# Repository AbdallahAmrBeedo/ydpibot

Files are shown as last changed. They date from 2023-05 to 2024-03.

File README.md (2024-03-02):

# **YDPIbot**

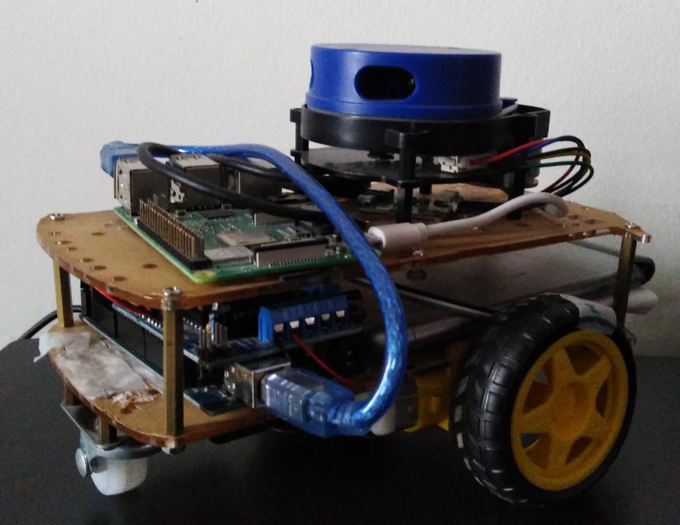
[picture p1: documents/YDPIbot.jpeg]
ydlidar X4


YDPIbot is an open platform differential drive mobile robot that uses a Raspberry Pi, an Arduino Mega, a YDLidar, a motor shield, an IMU, and encoders to perform autonomous navigation and mapping tasks. YDPIbot is an affordable and easy-to-assemble robot that is designed to be an educational tool for students and hobbyists who are interested in learning about robotics and autonomous systems.

---------------------------
# Assembly

To assemble YDPIbot, you will need the following components:

- Raspberry Pi 3 model B+
- YDLidar x4
- Arduino Mega
- Motor driver shield
- IMU (MPU6050)
- Optical encoders
- 2 DC motors
- 2 Wheels
- 1 Caster wheel
- Batteries with holder
- Power bank

Follow these steps to assemble YDPIbot:

1. Connect the Arduino Mega to the motor driver shield and the optical encoders and MPU6050 according to the pinout diagram provided in the documentation.
2. Connect the IMU to Raspberry Pi using the I2C interface and follow the instructions in the [mpu6050 pkg](https://github.com/PigeonSensei/pigeon_imu_driver/tree/master/mpu6050).
3. Mount the YDLidar on top of the robot using screws.
4. Mount the Raspberry Pi and the motor driver shield on the chassis of the robot using screws and standoffs.
5. Connect the DC motors to the motor driver shield and attach the wheels to the motor shafts.
6. Attach the optical encoders to the motors using the mountingbrackets provided in the kit.
7. Attach the caster wheel to the bottom of the robot chassis.
8. Install the batteries or power banks on the robot and connect them to the Arduino Mega and the motor driver shield.

---------------------------
# Installation

To use YDPIbot, you will need to install the following dependencies:

- [Python 3](https://www.python.org/downloads/)
- [Ubiquity Robotics image - Ubuntu 20.04](https://learn.ubiquityrobotics.com/noetic_pi_image_downloads) for rasberry pi
- [ROS Noetic](http://wiki.ros.org/noetic/Installation) - the ubiquity robotics image have ROS noetic already-
- [YDLidar pkg](https://github.com/PinkWink/ydlidar)
- [MPU6050](https://github.com/PigeonSensei/pigeon_imu_driver/tree/master/mpu6050)
- Robot Pose EKF
- Hector Mapping
- Rosserial
---------------------------
### Installing Ubuntu20.04 on Raspberry PI

We recommend installing Ubuntu 20.04 and ROS noetic on the Raspberry Pi using the Ubiquity Robotics image. Follow these steps to install Ubuntu 20.04 using the Ubiquity Robotics image:

1. Download the Ubiquity Robotics image for Raspberry Pi from the [Ubiquity Robotics](https://learn.ubiquityrobotics.comnoetic_pi_image_downloads)

2. Flash the image to an SD card using a tool like Raspberry Pi Imager.

3. Insert the SD card into the Raspberry Pi and power it on.

4. Follow the on-screen instructions to complete the Ubuntu 20.04 installation process.

---------------------------
### Installing YDlidar pkg

To install the YDLidar pkg, follow these steps:

1. Open a terminal on your Raspberry Pi.

2. Clone the YDLidar repository using the following command:

    `git clone https://github.com/PinkWink/ydlidar.git`

3. Follow the instructions in the [README file](https://github.com/PinkWink/ydlidar) to build the YDLidar pkg.

4. Run some demo with the lidar to check if it's working.

---------------------------
### Installing MPU6050 pkg

To install the MPU6050 pkg, follow these steps:

1. Open a terminal on your Raspberry Pi.

2. Clone the MPU6050 repository using the following command:

    `https://github.com/PigeonSensei/pigeon_imu_driver/tree/master/mpu6050`

3. Install wiringPi library from [here](http://wiringpi.com/download-and-install/)

4. Run some demo with the IMU to check if it's working.

---------------------------
### Installing YDPIbot pkg

To install the YDPIbot package, follow these steps:

1. Open a terminal on your Raspberry Pi or PC.

2. Navigate to your `catkin_ws/src` directory

3. Clone the YDPIbot repository using the following command:

    `git clone https://github.com/AbdallahAmrBeedo/ydpibot.git`

4. Navigate back to the main catkin_ws to build the pkg using the command:

    `catkin_make`

---------------------------
### Uploading Arduino Code

1. Open Arduino IDE and connect the arduino to your PC

2. Choose from tools/boards Arduino Mega 2560 and choose the port (Usually **/dev/ttyACM0** if you are running from Ubuntu)

3. Open the code in `~/catkin_ws/src/ydpibot/ydpibot_bringup/YDPIbot/YDPIbot.ino`

4. Upload the code and connect the Arduino to the raspberry pi.

---------------------------
## Usage
For using the robot hardware, just open a terminal on the Raspberry pi and run the following command:

`roslaunch ydpibot_bringup robot.launch`

and wait until you see the massage `Sensors calibrated, Start!`

Now, you can run any other pkg to do anything!

---------------------------

For using the robot simulation, just open a terminal on the PC and run the following command:

`roslaunch ydpibot_description robot.launch`

Now, you can run any other pkg to do anything!

---------------------------
## Contributing

We welcome contributions from other developers! If you would like to contribute to YDPIbot, please follow these guidelines:

1. Fork the YDPIbot repository to your own GitHub account.
2. Create a new branch for your feature or bug fix.
3. Make your changes and test them thoroughly.
4. Submit a pull request to the main YDPIbot repository with a clear description of your changes.

---------------------------
## Credits

YDPIbot was created by Abdallah Amr, Mostafa Osama, Tarek Shohdy, and Yomna Omar from Egypt-Japan University of Science and Technology. We would like to acknowledge the following libraries and tools that were used in the development of this project:

- [YDLidar SDK](https://www.ydlidar.com/products/view/5.html)
- [Adafruit Motor Shield library](https://learn.adafruit.com/adafruit-motor-shield/library-install)
- [Ubiquity Robotics Raspberry Pi Image](https://learn.ubiquityrobotics.comnoetic_pi_image_downloads)
- [MPU6050](https://github.com/PigeonSensei/pigeon_imu_driver/tree/master/mpu6050)

We would also like to thank the following people for their contributions to this project:

- Abdallah Amr (abdallah.amr@ejust.edu.eg)
- Mostafa Osama (mostafa.eshra@ejust.edu.eg)
- Tarek Shohdy (tarek.shohdy@ejust.edu.eg)
- Yomna Omar (yomna.mokhtar@ejust.edu.eg)

If you have any questions or feedback about YDPIbot, please contact us at abdallah.amr@ejust.edu.eg. We would love to hear from you!

---------------------------
## Future Work

- Add documentries (video - frames.pdf)
- Apply localizatin on gazebo simulation
- Odometry (options: try the encoders as it is, kalman filter between imu and encoders)
- Add reset odom service for the pose estimator
- Add Readme file for each pakage with how to use each one
- Add GUI for the bot
- Robot model is not moving in rviz while mapping

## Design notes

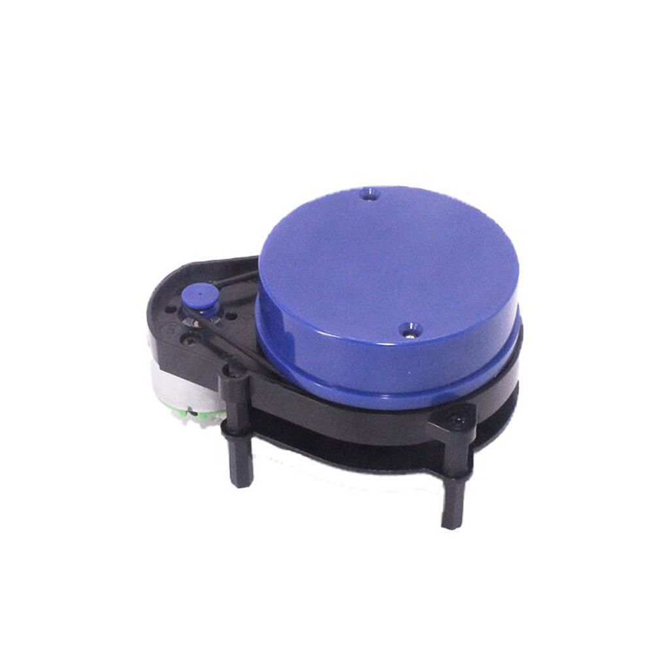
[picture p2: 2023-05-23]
documents/ydlidar.jpg

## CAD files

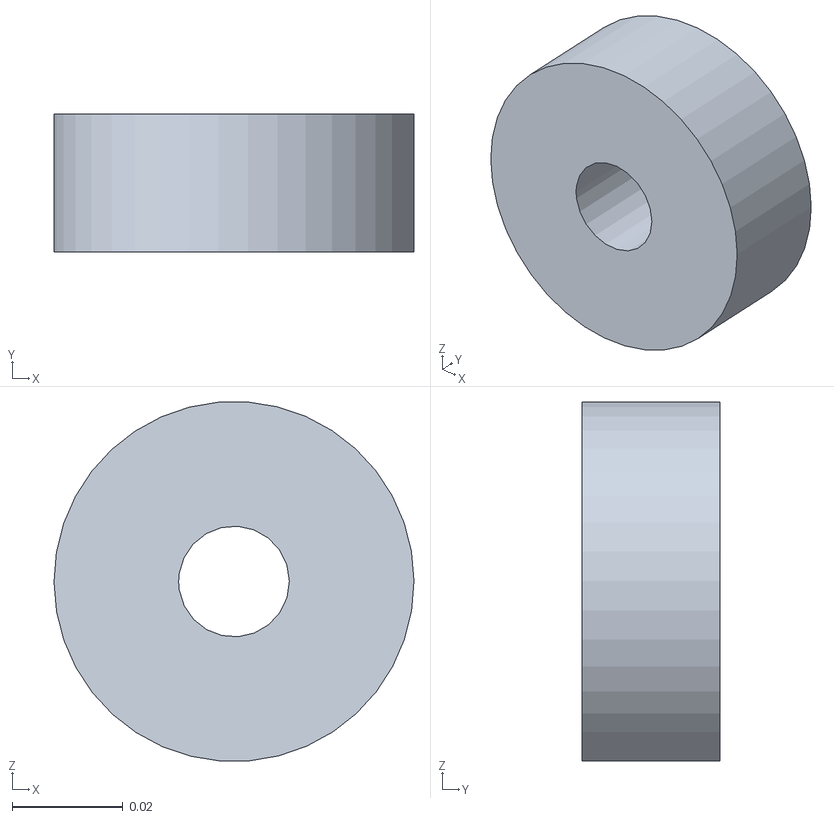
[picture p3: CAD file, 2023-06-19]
ydpibot_description/meshes/right_wheel.STL
0.065 x 0.025 x 0.0648

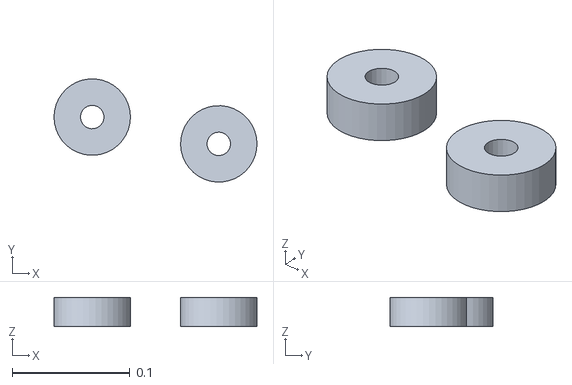
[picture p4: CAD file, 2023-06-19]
ydpibot_description/meshes/weight.STL
0.173 x 0.0876 x 0.025

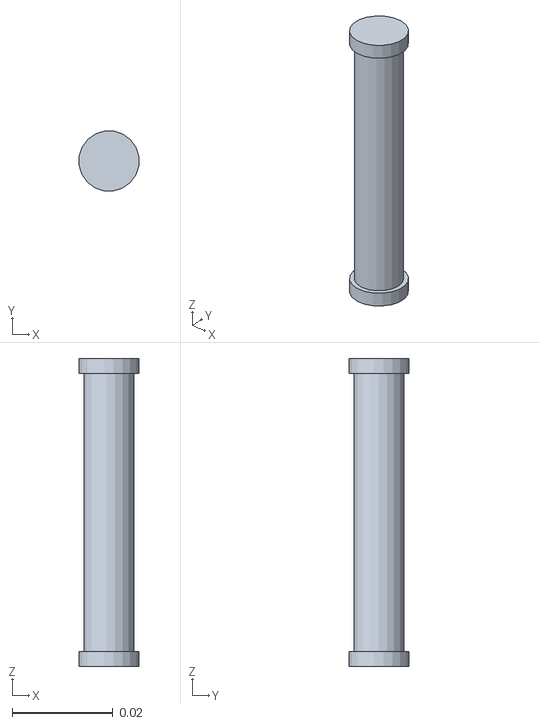
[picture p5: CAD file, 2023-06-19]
ydpibot_description/meshes/spacer3.STL
0.0119 x 0.0119 x 0.061

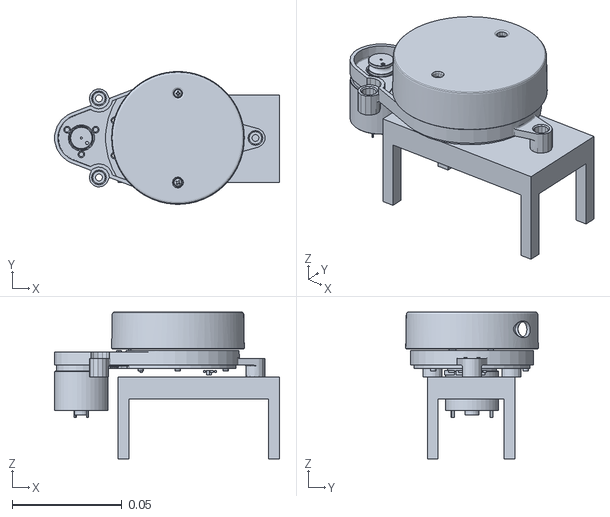
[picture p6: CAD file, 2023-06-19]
ydpibot_description/meshes/base_scan.STL
0.103 x 0.0604 x 0.0669

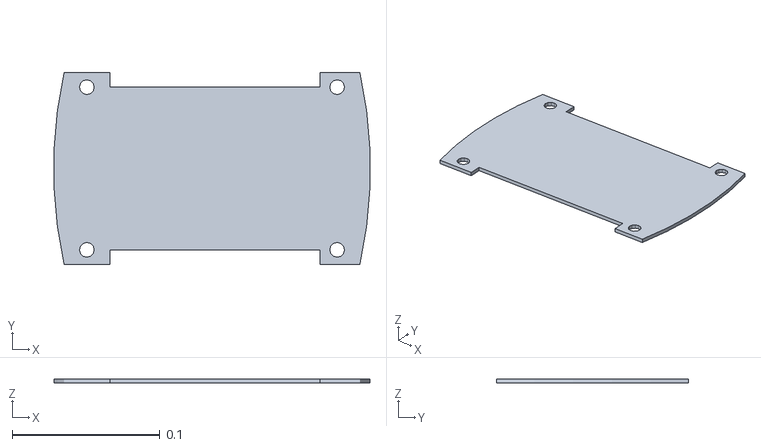
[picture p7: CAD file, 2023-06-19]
ydpibot_description/meshes/Upper_base.STL
0.214 x 0.13 x 0.003

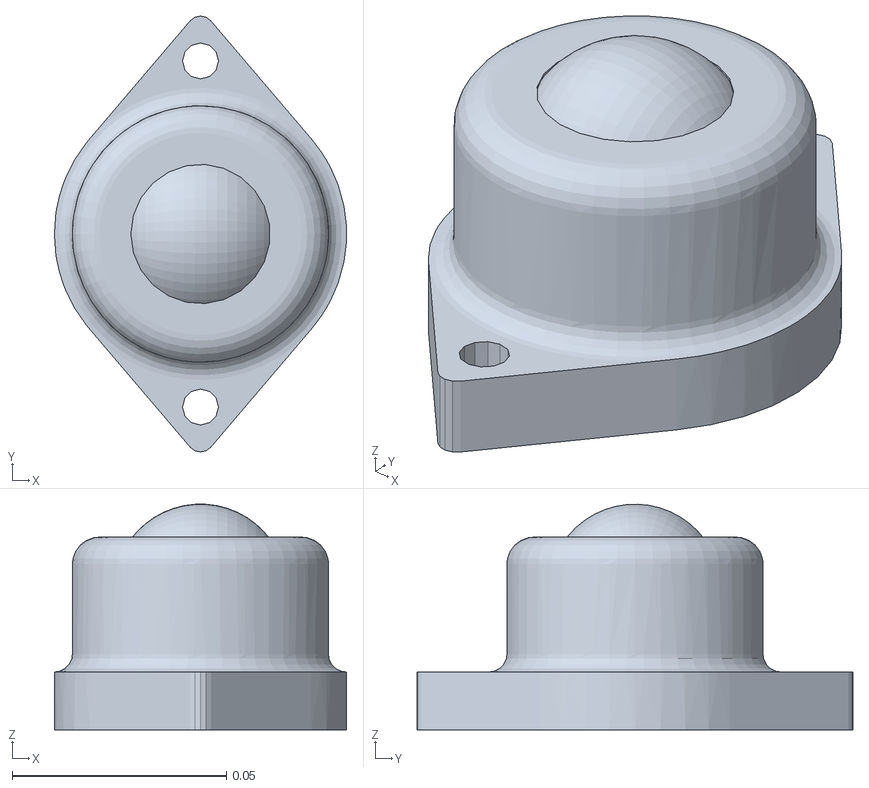
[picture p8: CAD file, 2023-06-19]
ydpibot_description/meshes/caster_wheel_.STL
0.0683 x 0.102 x 0.0527

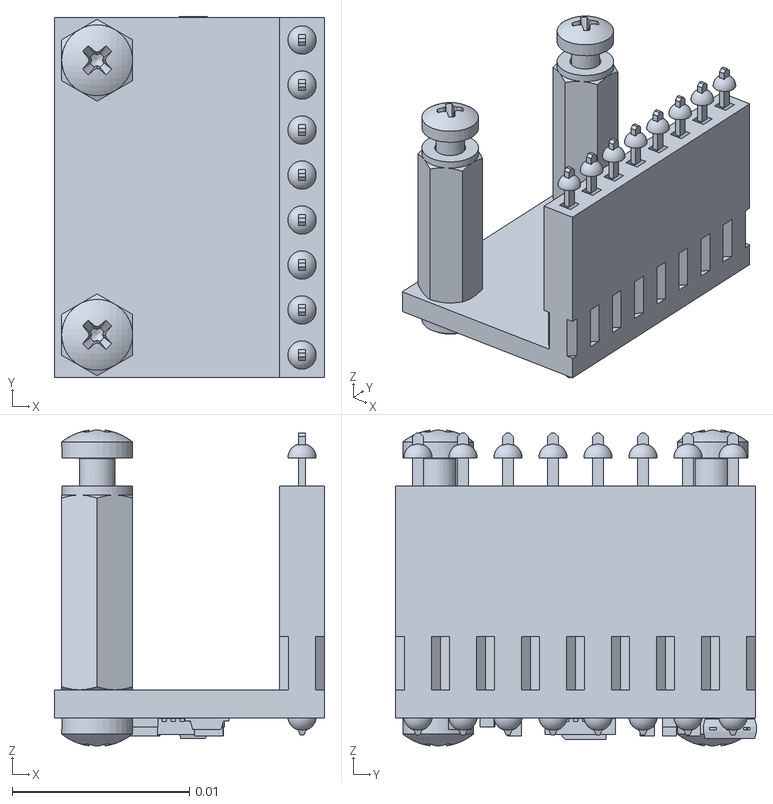
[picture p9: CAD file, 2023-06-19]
ydpibot_description/meshes/IMU.STL
0.0152 x 0.0204 x 0.0178

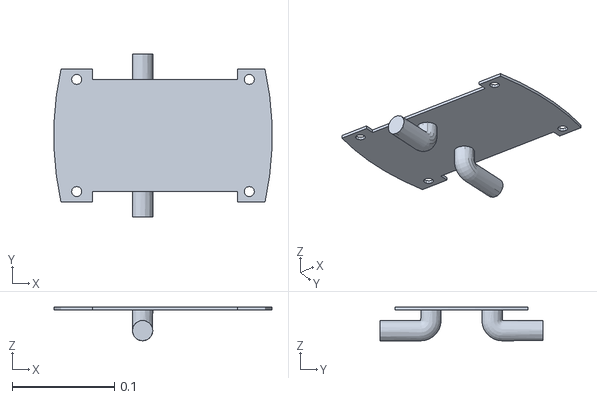
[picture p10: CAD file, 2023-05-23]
ydpibot_description/meshes/base_link.STL
0.214 x 0.16 x 0.033

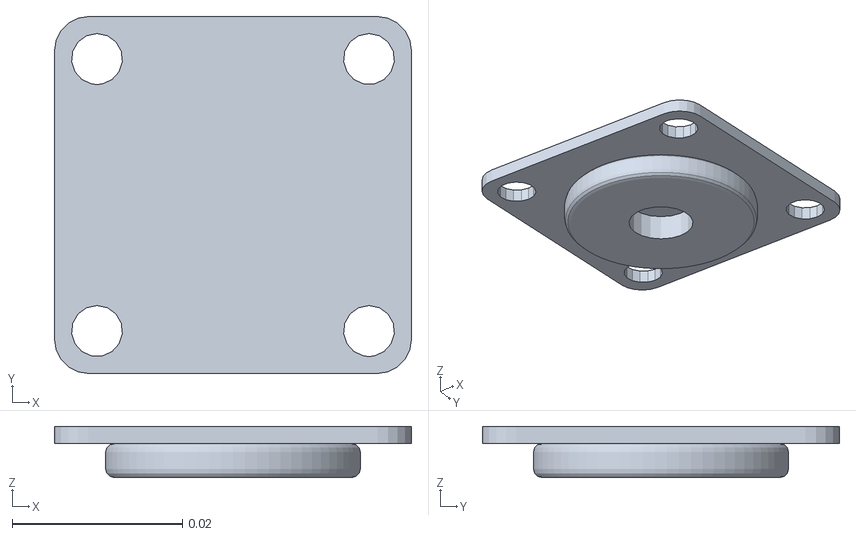
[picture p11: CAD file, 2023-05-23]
ydpibot_description/meshes/caster_wheel_base.STL
0.042 x 0.042 x 0.006

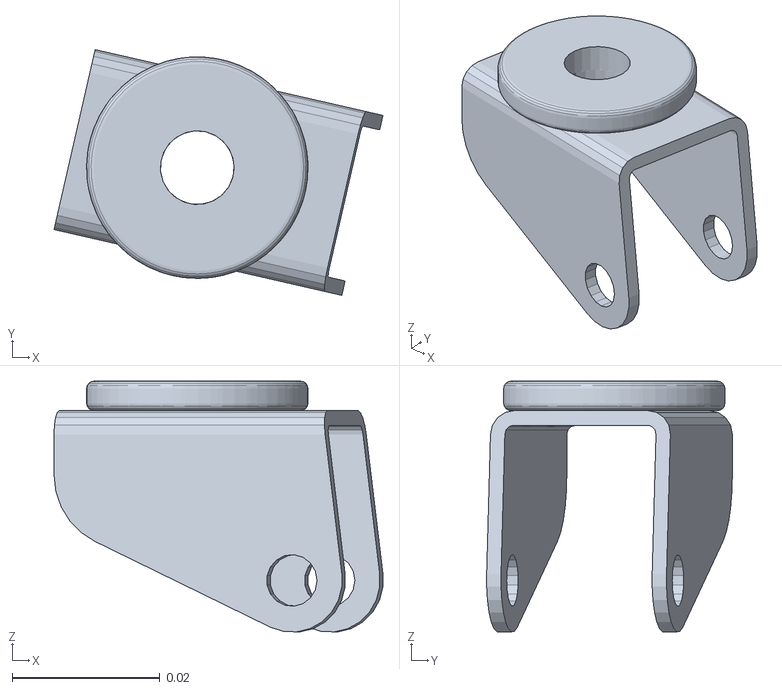
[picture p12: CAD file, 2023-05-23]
ydpibot_description/meshes/caster_wheel_cage.STL
0.0446 x 0.0333 x 0.034

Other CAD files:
ydpibot_description/meshes/spacer1.STL
ydpibot_description/meshes/spacer2.STL
ydpibot_description/meshes/spacer4.STL
ydpibot_description/meshes/Lower_Base.STL
ydpibot_description/meshes/left_wheel.STL
ydpibot_description/meshes/Base_upper.STL
ydpibot_description/meshes/Lidar.STL
ydpibot_description/meshes/Wheel1.STL
ydpibot_description/meshes/Caster Wheel Base.STL
ydpibot_description/meshes/Caster Wheel cage.STL
ydpibot_description/meshes/Caster Wheel.STL
ydpibot_description/meshes/Wheel2.STL
ydpibot_description/meshes/caster_wheel.STL

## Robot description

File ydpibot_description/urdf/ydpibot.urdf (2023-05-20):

<?xml version="1.0" encoding="utf-8"?>
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
<robot name="ydpibot">
  <link name="base_link">
    <inertial>
      <origin xyz="0.093495 0.094111 0.17099" rpy="0 0 0" />
      <mass value="0.11353" />
      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
    </inertial>
    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
  </link>
  <link name="Base_upper">
    <inertial>
      <origin xyz="-0.00023228 0.0015 2.7756E-17" rpy="0 0 0" />
      <mass value="0.072243" />
      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
    </inertial>
    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
  </link>
  <joint name="Base_upper_joint" type="fixed">
    <origin xyz="0.10092 -0.17099 0.13642" rpy="1.5708 0 0" />
    <parent link="base_link" />
    <child link="Base_upper" />
    <axis xyz="0 0 0" />
  </joint>
  <link name="spacer1">
    <inertial>
      <origin xyz="8.3267E-17 -0.017 -2.7756E-17" rpy="0 0 0" />
      <mass value="0.0038202" />
      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
    </inertial>
    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
  </link>
  <joint name="spacer1_joint" type="continuous">
    <origin xyz="0.084615 0 -0.055" rpy="0 0.33559 0" />
    <parent link="Base_upper" />
    <child link="spacer1" />
    <axis xyz="0 1 0" />
  </joint>
  <link name="spacer2">
    <inertial>
      <origin xyz="1.3878E-16 -0.017 5.5511E-17" rpy="0 0 0" />
      <mass value="0.0038202" />
      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
    </inertial>
    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
  </link>
  <joint name="spacer2_joint" type="continuous">
    <origin xyz="0.084615 0 0.055" rpy="0 0.33674 0" />
    <parent link="Base_upper" />
    <child link="spacer2" />
    <axis xyz="0 1 0" />
  </joint>
  <link name="spacer3">
    <inertial>
      <origin xyz="0 -0.017 0" rpy="0 0 0" />
      <mass value="0.0038202" />
      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
    </inertial>
    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
  </link>
  <joint name="spacer3_joint" type="continuous">
    <origin xyz="-0.084615 0 -0.055" rpy="0 0.33674 0" />
    <parent link="Base_upper" />
    <child link="spacer3" />
    <axis xyz="0 1 0" />
  </joint>
  <link name="spacer4">
    <inertial>
      <origin xyz="-2.4286E-17 -0.017 2.7756E-17" rpy="0 0 0" />
      <mass value="0.0038202" />
      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
    </inertial>
    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
  </link>
  <joint name="spacer4_joint" type="continuous">
    <origin xyz="-0.084615 0 0.055" rpy="0 0.14715 0" />
    <parent link="Base_upper" />
    <child link="spacer4" />
    <axis xyz="0 1 0" />
  </joint>
  <link name="Lidar">
    <inertial>
      <origin xyz="-0.010012 -1.8596E-15 -0.015783" rpy="0 0 0" />
      <mass value="0.032124" />
      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
    </inertial>
    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
  </link>
  <joint name="Lidar_joint" type="fixed">
    <origin xyz="-0.039725 0.04948 0" rpy="1.5708 0 -3.1416" />
    <parent link="Base_upper" />
    <child link="Lidar" />
    <axis xyz="0 0 0" />
  </joint>
  <link name="Wheel1">
    <inertial>
      <origin xyz="0 -1.3878E-17 0.0125" rpy="0 0 0" />
      <mass value="0.075104" />
      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
    </inertial>
    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
  </link>
  <joint name="Wheel1_joint" type="continuous">
    <origin xyz="0.080916 -0.090994 0.079422" rpy="1.5708 0 0" />
    <parent link="base_link" />
    <child link="Wheel1" />
    <axis xyz="0 0 1" />
  </joint>
  <link name="Wheel2">
    <inertial>
      <origin xyz="0 0 0.0125" rpy="0 0 0" />
      <mass value="0.075104" />
      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
    </inertial>
    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
  </link>
  <joint name="Wheel2_joint" type="continuous">
    <origin xyz="0.080916 -0.22599 0.079422" rpy="1.5708 0 0" />
    <parent link="base_link" />
    <child link="Wheel2" />
    <axis xyz="0 0 1" />
  </joint>
  <link name="Caster Wheel Base">
    <inertial>
      <origin xyz="0.017052 0.003709 -0.0125" rpy="0 0 0" />
      <mass value="0.044833" />
      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
    </inertial>
    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
  </link>
  <joint name="Caster Wheel Base_joint" type="fixed">
    <origin xyz="0.15791 -0.18349 0.093422" rpy="1.5708 0 0" />
    <parent link="base_link" />
    <child link="Caster Wheel Base" />
    <axis xyz="0 0 0" />
  </joint>
  <link name="Caster Wheel cage">
    <inertial>
      <origin xyz="0.019414 -0.0053453 -0.0125" rpy="0 0 0" />
      <mass value="0.056621" />
      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
    </inertial>
    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
  </link>
  <joint name="Caster Wheel cage_joint" type="continuous">
    <origin xyz="0.0037189 -0.004 0.0039088" rpy="0 0.25588 0" />
    <parent link="Caster Wheel Base" />
    <child link="Caster Wheel cage" />
    <axis xyz="0 0 0" />
  </joint>
  <link name="Caster Wheel">
    <inertial>
      <origin xyz="1.3878E-17 0 2.7756E-17" rpy="0 0 0" />
      <mass value="0.017472" />
      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
    </inertial>
    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
  </link>
  <joint name="Caster Wheel_joint" type="fixed">
    <origin xyz="0.033052 -0.023 -0.0125" rpy="0 0 1.7635" />
    <parent link="Caster Wheel cage" />
    <child link="Caster Wheel" />
    <axis xyz="0 0 0" />
  </joint>
</robot>

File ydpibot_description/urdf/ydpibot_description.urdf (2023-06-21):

<?xml version="1.0" encoding="utf-8"?>
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
<robot name="ydpibot_description">
  <link name="base_link">
    <inertial>
      <origin xyz="-0.0093884 -5.5511E-17 0.047189" rpy="0 0 0" />
      <mass value="1.11353" />
      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
    </inertial>
    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
  </link>
  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
  <link name="base_footprint">
  </link>
  <joint name="base_footprint" type="fixed">
    <origin xyz="0 0 0" rpy="0 0 0" />
    <parent link="base_link" />
    <child link="base_footprint" />
    <axis xyz="0 0 0" />
  </joint>
  <link name="Upper_base">
    <inertial>
      <origin xyz="-0.00023228 0 0.0165" rpy="0 0 0" />
      <mass value="0.072243" />
      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
    </inertial>
    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
  </link>
  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
  <joint name="Upper_base" type="fixed">
    <origin xyz="-0.0019675 0 0.0895" rpy="0 0 0" />
    <parent link="base_link" />
    <child link="Upper_base" />
    <axis xyz="0 0 0" />
  </joint>
  <link name="spacer1">
    <inertial>
      <origin xyz="2.7756E-17 2.7756E-17 -0.0095" rpy="0 0 0" />
      <mass value="0.0049983" />
      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
    </inertial>
    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
  </link>
  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
  <joint name="spacer1_joint" type="fixed">
    <origin xyz="0.084615 0.055 0" rpy="0 0 0" />
    <parent link="Upper_base" />
    <child link="spacer1" />
    <axis xyz="0 0 0" />
  </joint>
  <link name="spacer2">
    <inertial>
      <origin xyz="4.1633E-16 -2.7756E-17 -0.0095" rpy="0 0 0" />
      <mass value="0.0049983" />
      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
    </inertial>
    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
  </link>
  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
  <joint name="spacer2_joint" type="fixed">
    <origin xyz="0.084615 -0.055 0" rpy="0 0 0" />
    <parent link="Upper_base" />
    <child link="spacer2" />
    <axis xyz="0 0 0" />
  </joint>
  <link name="spacer3">
    <inertial>
      <origin xyz="-1.5474E-15 2.7756E-17 -0.0095" rpy="0 0 0" />
      <mass value="0.0049983" />
      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
    </inertial>
    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
  </link>
  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
  <joint name="spacer3_joiint" type="fixed">
    <origin xyz="-0.084615 -0.055 0" rpy="0 0 0" />
    <parent link="Upper_base" />
    <child link="spacer3" />
    <axis xyz="0 0 0" />
  </joint>
  <link name="spacer4">
    <inertial>
      <origin xyz="-1.5959E-15 1.3878E-17 -0.0095" rpy="0 0 0" />
      <mass value="0.0049983" />
      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
    </inertial>
    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
  </link>
  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
  <joint name="spacer4_joint" type="fixed">
    <origin xyz="-0.084615 0.055 0" rpy="0 0 0" />
    <parent link="Upper_base" />
    <child link="spacer4" />
    <axis xyz="0 0 0" />
  </joint>
  <link name="base_scan">
    <inertial>
      <origin xyz="0.010012 8.3267E-17 -0.00078299" rpy="0 0 0" />
      <mass value="0.032124" />
      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
    </inertial>
    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
  </link>
    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
  <joint name="base_scan_joint" type="fixed">
    <origin xyz="-0.039725 0 0.13948" rpy="0 0 0" />
    <parent link="base_footprint" />
    <child link="base_scan" />
    <axis xyz="0 0 0" />
  </joint>
  <link name="right_wheel">
    <inertial>
      <origin xyz="-6.9389E-18 -0.0125 6.9389E-18" rpy="0 0 0" />
      <mass value="0.1" />
      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
    </inertial>
    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
  </link>
  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
  <joint name="right_wheel_joint" type="continuous">
    <origin xyz="-0.021967 -0.055 0.0325" rpy="0 0 0" />
    <parent link="base_link" />
    <child link="right_wheel" />
    <axis xyz="0 1 0" />
  </joint>
  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
  <link name="left_wheel">
    <inertial>
      <origin xyz="-4.7184E-16 -0.0125 4.7184E-16" rpy="0 0 0" />
      <mass value="0.1" />
      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
    </inertial>
    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
  </link>
  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
  <joint name="left_wheel_joint" type="continuous">
    <origin xyz="-0.021967 0.08 0.0325" rpy="0 0 0" />
    <parent link="base_link" />
    <child link="left_wheel" />
    <axis xyz="0 1 0" />
  </joint>
  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
  <link name="caster_wheel_">
    <inertial>
      <origin xyz="-9.7039E-09 -9.3993E-09 0.0022919" rpy="0 0 0" />
      <mass value="0.4" />
      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
    </inertial>
    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
  </link>  
  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
  <joint name="caster_wheel__joint" type="fixed">
    <origin xyz="0.069075 0 0.033565" rpy="-3.1416 0 0" />
    <parent link="base_link" />
    <child link="caster_wheel_" />
    <axis xyz="0 0 0" />
  </joint>
  <link name="IMU">
    <inertial>
      <origin xyz="-0.021085 4.0683E-05 0.0050175" rpy="0 0 0" />
      <mass value="0.0014392" />
      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
    </inertial>
    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
  </link>
  <joint name="IMU_joint" type="fixed">
    <origin xyz="0.000205 0 0.04234" rpy="1.5708 0 0" />
    <parent link="base_link" />
    <child link="IMU" />
    <axis xyz="0 0 0" />
  </joint>
  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

</robot>

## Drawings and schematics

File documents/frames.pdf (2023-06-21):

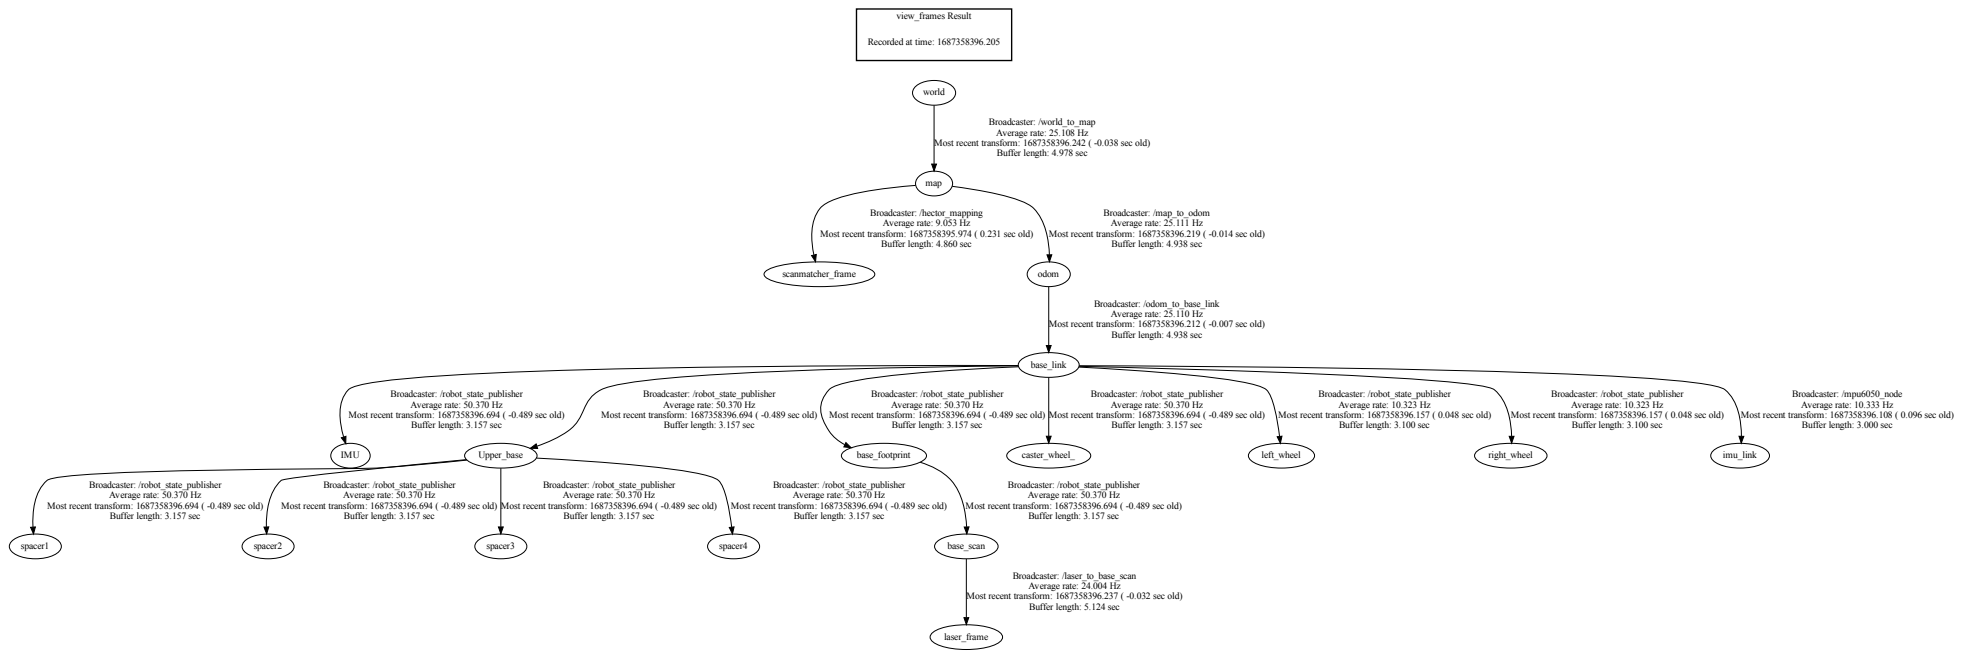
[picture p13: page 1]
view_frames Result; world; map; scanmatcher_frame; odom; base_scan; laser_frame; base_link; IMU; Upper_base; base_footprint; caster_wheel_; left_wheel; right_wheel; imu_link; spacer1; spacer2; spacer3; spacer4

Recorded at time: 1687358396.205

Broadcaster: /world_to_map
Average rate: 25.108 Hz

Most recent transform: 1687358396.242 ( -0.038 sec old)

Buffer length: 4.978 sec

Broadcaster: /hector_mapping
Average rate: 9.053 Hz

Broadcaster: /map_to_odom
Average rate: 25.111 Hz

Most recent transform: 1687358395.974 ( 0.231 sec old)

Most recent transform: 1687358396.219 ( -0.014 sec old)

Buffer length: 4.860 sec

Buffer length: 4.938 sec

Broadcaster: /odom_to_base_link
Average rate: 25.110 Hz

Most recent transform: 1687358396.212 ( -0.007 sec old)

Broadcaster: /robot_state_publisher
Average rate: 50.370 Hz

Average rate: 10.323 Hz

Broadcaster: /mpu6050_node
Average rate: 10.333 Hz

Most recent transform: 1687358396.694 ( -0.489 sec old)

Most recent transform: 1687358396.157 ( 0.048 sec old)

Most recent transform: 1687358396.108 ( 0.096 sec old)

Buffer length: 3.157 sec

Buffer length: 3.100 sec

Buffer length: 3.000 sec

Broadcaster: /laser_to_base_scan
Average rate: 24.004 Hz

Most recent transform: 1687358396.237 ( -0.032 sec old)

Buffer length: 5.124 sec

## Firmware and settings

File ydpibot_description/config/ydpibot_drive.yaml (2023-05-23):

mobile_base_controller:
  type        : "diff_drive_controller/DiffDriveController"
  left_wheel  : 'left_wheel_joint'
  right_wheel : 'right_wheel_joint'
  publish_rate: 50.0               # default: 50
  pose_covariance_diagonal : [0.001, 0.001, 1000000.0, 1000000.0, 1000000.0, 1000.0]
  twist_covariance_diagonal: [0.001, 0.001, 1000000.0, 1000000.0, 1000000.0, 1000.0]

  # Wheel separation and diameter. These are both optional.
  # diff_drive_controller will attempt to read either one or both from the
  # URDF if not specified as a parameter
  wheel_separation : 0.137
  wheel_radius : 0.0325

  # Wheel separation and radius multipliers
  wheel_separation_multiplier: 1.0 # default: 1.0
  wheel_radius_multiplier    : 1.0 # default: 1.0

  # Velocity commands timeout [s], default 0.5
  cmd_vel_timeout: 0.25

  # Base frame_id
  base_frame_id: base_link #default: base_link

  # Velocity and acceleration limits
  # Whenever a min_* is unspecified, default to -max_*
  linear:
    x:
      has_velocity_limits    : true
      max_velocity           : 1.0  # m/s
      min_velocity           : -0.5 # m/s
      has_acceleration_limits: true
      max_acceleration       : 0.8  # m/s^2
      min_acceleration       : -0.4 # m/s^2
      has_jerk_limits        : true
      max_jerk               : 5.0  # m/s^3
  angular:
    z:
      has_velocity_limits    : true
      max_velocity           : 1.7  # rad/s
      has_acceleration_limits: true
      max_acceleration       : 1.5  # rad/s^2
      has_jerk_limits        : true
      max_jerk               : 2.5  # rad/s^3

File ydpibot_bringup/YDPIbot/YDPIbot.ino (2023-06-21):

/*
 * This Arduino code implements a ROS node that subscribes to the "/motor_speeds" topic with Int16MultiArray message,
 * and publishes to the "/imu" and "/odom" topics with IMU and encoder odom messages.
 *
 * The node reads the motor speeds from the "/motor_speeds" topic and computes the linear acceleration and angular velocity
 * using the encoder interrupt readings. It publishes the computed linear acceleration, angular velocity, and orientation
 * to the "/imu" topic as an IMU message, and the encoder odom readings to the "/odom" topic as an odom message.
 *
 * This node assumes that the robot has two independently controlled wheels and encoders, and that the motor speeds
 * are given as an array of two integers representing the PWM values.
 *
 * Usage:
 *  - Upload this code to your Arduino board.
 *  - Run the ROS core.
 *  - Start the node with "rosrun rosserial_arduino serial_node.py /dev/ttyACM0".
 *
 * Subscribed Topics:
 *  - /motor_speeds (std_msgs/Int16MultiArray): The motor speeds of the robot.
 *
 * Published Topics:
 *  - /imu (sensor_msgs/Imu): The linear acceleration, angular velocity, and orientation of the robot.
 *  - /odom (nav_msgs/Odometry): The encoder odom readings of the robot.
 *
 * Parameters:
 *  - ~encoder_resolution (int, default: 4096): The encoder resolution in counts per revolution.
 *
 * This code was developed by: 
 *  - Abdallah Amr (Egypt Japan University of Science and Technology)
 *  - Mostafa Osama (Egypt Japan University of Science and Technology)
 *  - Tarek Shohdy (Egypt Japan University of Science and Technology)
 *  - Yomna Omar (Egypt Japan University of Science and Technology)
 */

#include <AFMotor.h>
#include <ros.h>
#include <ros/time.h>
#include <std_msgs/Int16MultiArray.h>
#include <std_msgs/Int16.h>

ros::NodeHandle nh;

// motor driver library
AF_DCMotor Right_Motor(2);
AF_DCMotor Left_Motor(1);

// velocities and directions
int PWM_r = 0;
int PWM_l = 0;
int Dir_r = RELEASE;
int Dir_l = RELEASE;

float t = 0;

void motorsCb(const std_msgs::Int16MultiArray& PWM){
  PWM_r = PWM.data[0];
  PWM_l = PWM.data[1];
  if (PWM_r == 0){
    Dir_r = RELEASE;
    }
  else{
    Dir_r = PWM_r / abs(PWM_r); // Forward
    if (Dir_r == -1) Dir_r = 2; //Backward
  }
  if (PWM_l == 0){
    Dir_l = RELEASE;
    }
  else{
    Dir_l = PWM_l / abs(PWM_l); // Forward
    if (Dir_l == -1) Dir_l = 2; //Backward    
  }
  
  Right_Motor.setSpeed(abs(PWM_r));
  Left_Motor.setSpeed(abs(PWM_l));
  Right_Motor.run(Dir_r);
  Left_Motor.run(Dir_l);
  delay(10);
}

ros::Subscriber<std_msgs::Int16MultiArray> motors("/motor_speeds", &motorsCb);

std_msgs::Int16 right_ticks;
ros::Publisher right_wheel("/right_ticks", &right_ticks);
std_msgs::Int16 left_ticks;
ros::Publisher left_wheel("/left_ticks", &left_ticks);

void setup() 
{
  attachInterrupt(digitalPinToInterrupt(18),pub_Rturns,RISING);
  attachInterrupt(digitalPinToInterrupt(19),pub_Lturns,RISING);
  nh.initNode();
  nh.advertise(right_wheel);
  nh.advertise(left_wheel);
  nh.subscribe(motors);
}

void loop() 
{
  nh.spinOnce();
  delay(1);
}

void pub_Rturns(){  
  if (Dir_r == FORWARD) right_ticks.data += 1;
  else if (Dir_r == BACKWARD) right_ticks.data -= 1;
  right_wheel.publish(&right_ticks);
  }

void pub_Lturns(){
  if (Dir_l == FORWARD) left_ticks.data += 1;
  else if (Dir_l == BACKWARD) left_ticks.data -= 1;
  left_wheel.publish(&left_ticks);
  }

void odom(){
  
}

float moving_average_filter(float new_reading,float old_reading, float alpha){
 float filtered_reading = alpha*new_reading + (1-alpha)*old_reading;
 return filtered_reading;
  
  }

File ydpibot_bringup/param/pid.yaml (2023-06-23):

x: {
  kp: 1,
  ki: 0,
  kd: 0,
  windup: 0.1
  }
w: {
  kp: 6.4,
  ki: 0.17,
  kd: 0.05,
  windup: 0.1
  }

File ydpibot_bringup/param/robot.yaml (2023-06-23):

wheel_base: 0.137
wheel_radius: 0.0325

max_speed: 230
min_speed: -230

max_vx: 0.5
min_vx: -0.5

max_wz: 1
min_wz: -1

encoder_resolution: 100

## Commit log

2023-05-20 added urdf V1.0
    [Base_upper.STL, Caster Wheel Base.STL, Caster Wheel cage.STL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]
2023-05-20 add arduino code
2023-05-20 arduino imu updated
2023-05-21 added reconfigure
    [pid.cfg, robot.cfg]
2023-05-21 update imuCB
2023-05-22 update describtion
    [Base_upper.STL, Caster Wheel Base.STL, Caster Wheel cage.STL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]
2023-05-22 update readme+descibtion
    [ydpibot.urdf]
2023-05-22 update description
    [Base_upper.STL, Caster Wheel Base.STL, Caster Wheel cage.STL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]
2023-05-23 perfect description
    [Upper_base.STL, base_link.STL, base_scan.STL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]
2023-05-23 gazebo+rviz updated
    [ydpibot_description.urdf]
2023-05-24 update slam
    [ydpibot_description.urdf]
2023-06-16 edit arduino
2023-06-21 rviz mapping file
    [ydpibot_description.urdf]
2023-06-21 edit urdf
    [ydpibot_description.urdf]
